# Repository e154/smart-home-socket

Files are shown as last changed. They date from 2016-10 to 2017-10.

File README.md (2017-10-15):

Автомат управления розетками/нагрузками
---------------------------------------

[Project site](https://e154.github.io/smart-home/) |
[Server](https://github.com/e154/smart-home/) |
[Configurator](https://github.com/e154/smart-home-configurator/) |
[Node](https://github.com/e154/smart-home-node/) |
[Development Tools](https://github.com/e154/smart-home-tools/) |
[Smart home Socket](https://github.com/e154/smart-home-socket/)



##### Функции
    Контроль температуры силового блока
    Включение/Выключения по команде управляющего сервера
    Контроль наличия сети/фазы

##### Общение с сервером
    Общение происходит по линии связи rs485, с помощью модифицированного 
    протокола MODBUS ASCII

##### Поведение автомата

    состояния:
    включен/выключен

    температура:
    в пределах нормы
    за пределами нормы

    комманды консоли:
    запрос состояния
          температура
          фаза
          вкл/выкл
          максимальный предел температуры
    включить
    выключить

##### Список компонентов

    Qty Value            Device                  Package         Parts              Description          
    1                    CPOL-EUE2,5-6E          E2,5-6E         C12                POLARIZED CAPACITOR, 
    1                    LEDCHIPLED_0805         CHIPLED_0805    LED2               LED                  
    5                    M01NOSILK-KIT           1X01NS-KIT      J1, J2, J3, J6, J7 Header 1             
    3                    M01PTH_NO_SILK_YES_STOP 1X01_NO_SILK    J4, J5, TEMP       Header 1             
    1                    MA03-2                  MA03-2          ISP                PIN HEADER           
    4                    MA04-1                  MA04-1          SV1, SV2, SV3, SV5 PIN HEADER           
    1   0.05mF           C-EUC0805               C0805           C6                 CAPACITOR, European  
    5   0.1              C-EUC0805               C0805           C1, C4, C5, C7, C8 CAPACITOR, European  
    2   10K              R-EU_M0805              M0805           R8, R12            RESISTOR, European s 
    3   10K              R-EU_R0805              R0805           R1, R13, R14       RESISTOR, European s 
    1   120R             R-EU_R0805              R0805           R17                RESISTOR, European s 
    1   16MHz            CRYSTALHC49U70          HC49U70         Q1                 CRYSTAL              
    1   1K               R-EU_M0805              M0805           R10                RESISTOR, European s 
    1   1K               R-EU_M1206              M1206           R9                 RESISTOR, European s 
    1   1K               R-EU_R0805              R0805           R2                 RESISTOR, European s 
    2   22p              C-EUC0805               C0805           C2, C3             CAPACITOR, European  
    3   330              R-EU_M0805              M0805           R3, R4, R5         RESISTOR, European s 
    1   560K             R-EU_M0805              M0805           R7                 RESISTOR, European s 
    2   560R             R-EU_R0805              R0805           R15, R16           RESISTOR, European s 
    1   78L05Z           78L05Z                  TO92            IC3                Positive VOLTAGE REG 
    2   82K              R-EU_0309/10            0309/10         R6, R11            RESISTOR, European s 
    1   AZ8-FORM-C       AZ8-FORM-C              AZ8             K1                 MINIATURE PC BOARD R 
    2   BC847            NPNSOT23                SOT-23          T2, T3             NPN TRANSISTOR       
    1   BT138-V          BT138-V                 TO220BV         T1                 TRIAC                
    2   DBDB101G         DBDB101G                DB              B1, B2             Single Phase 1.0 AMP 
    1   F/TMB            F/TMB                   F/TMB           SG1                BUZZER Source: Buerk 
    1   MAX481CSA        MAX481CSA               SO08            IC2                RS485 TRANSEIVER     
    1   MEGA48/88/168-AU MEGA48/88/168-AU        TQFP32-08       IC1                                     
    2   MKDSN1,5/2-5,08  MKDSN1,5/2-5,08         MKDSN1,5/2-5,08 X1, X2             MKDSN 1,5/ 2-5,08 Pr 
    1   MOC3031M         MOC3031M                DIL06           OK2                6-Pin DIP Zero-Cross 
    2   PC817            PC817                   DIL04           OK1, OK3           SHARP OPTO COUPLER   

##### Фоты
   
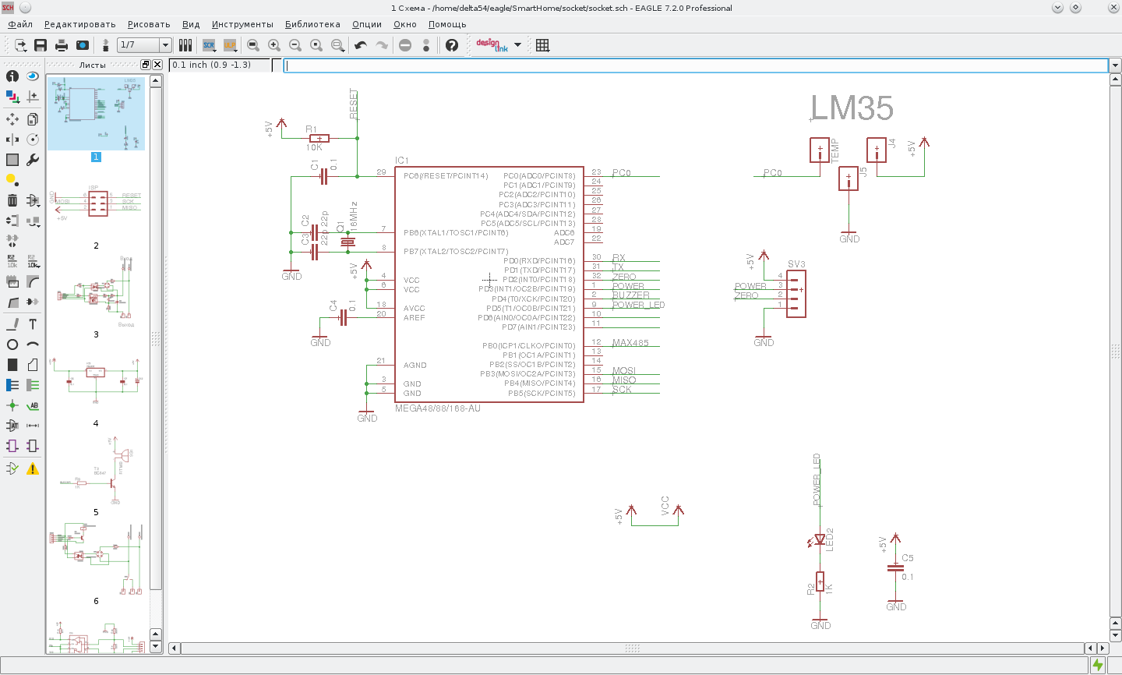
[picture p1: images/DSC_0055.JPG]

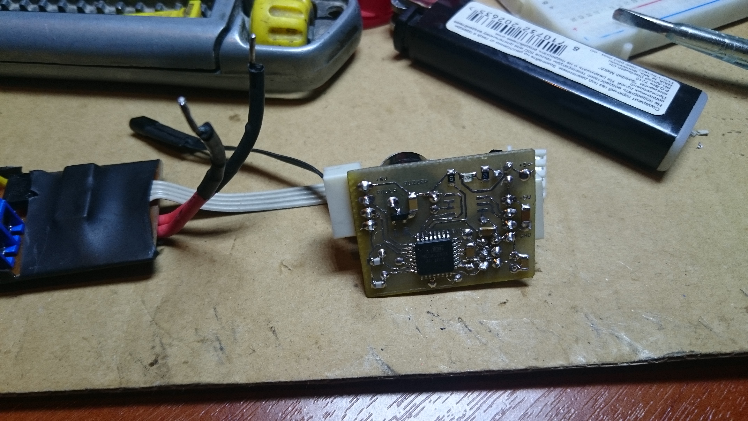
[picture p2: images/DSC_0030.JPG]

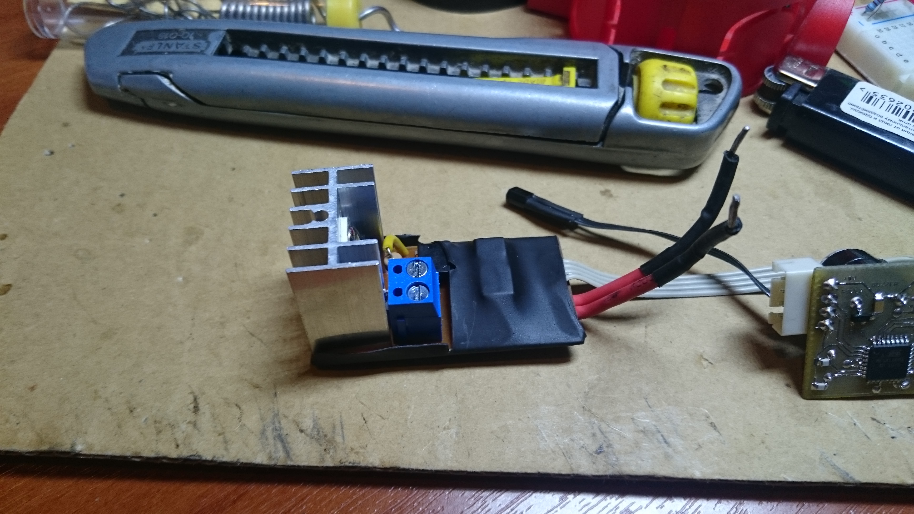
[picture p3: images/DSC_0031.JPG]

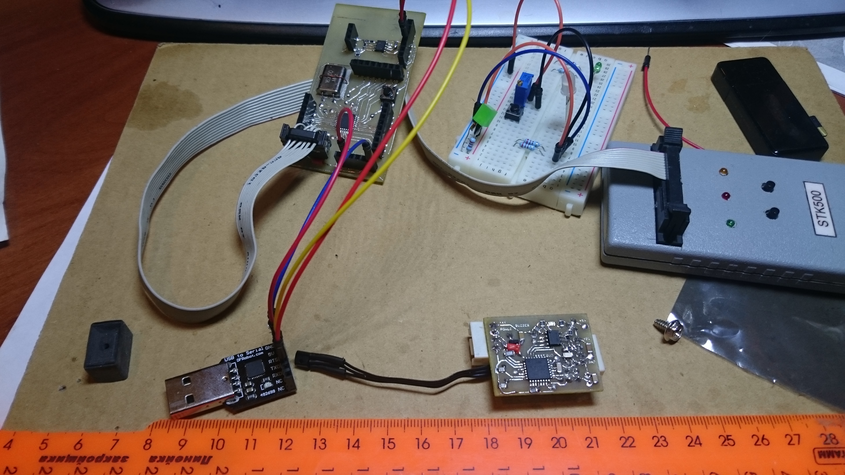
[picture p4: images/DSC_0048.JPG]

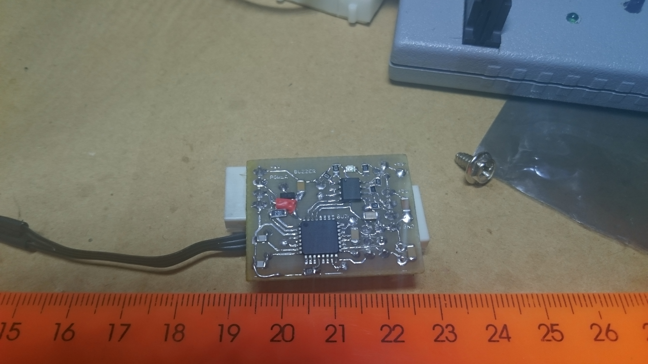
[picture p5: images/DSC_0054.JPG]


#### LICENSE

Smart home socket is licensed under the [MIT License (MIT)](https://github.com/e154/smart-home-socket/blob/master/LICENSE).

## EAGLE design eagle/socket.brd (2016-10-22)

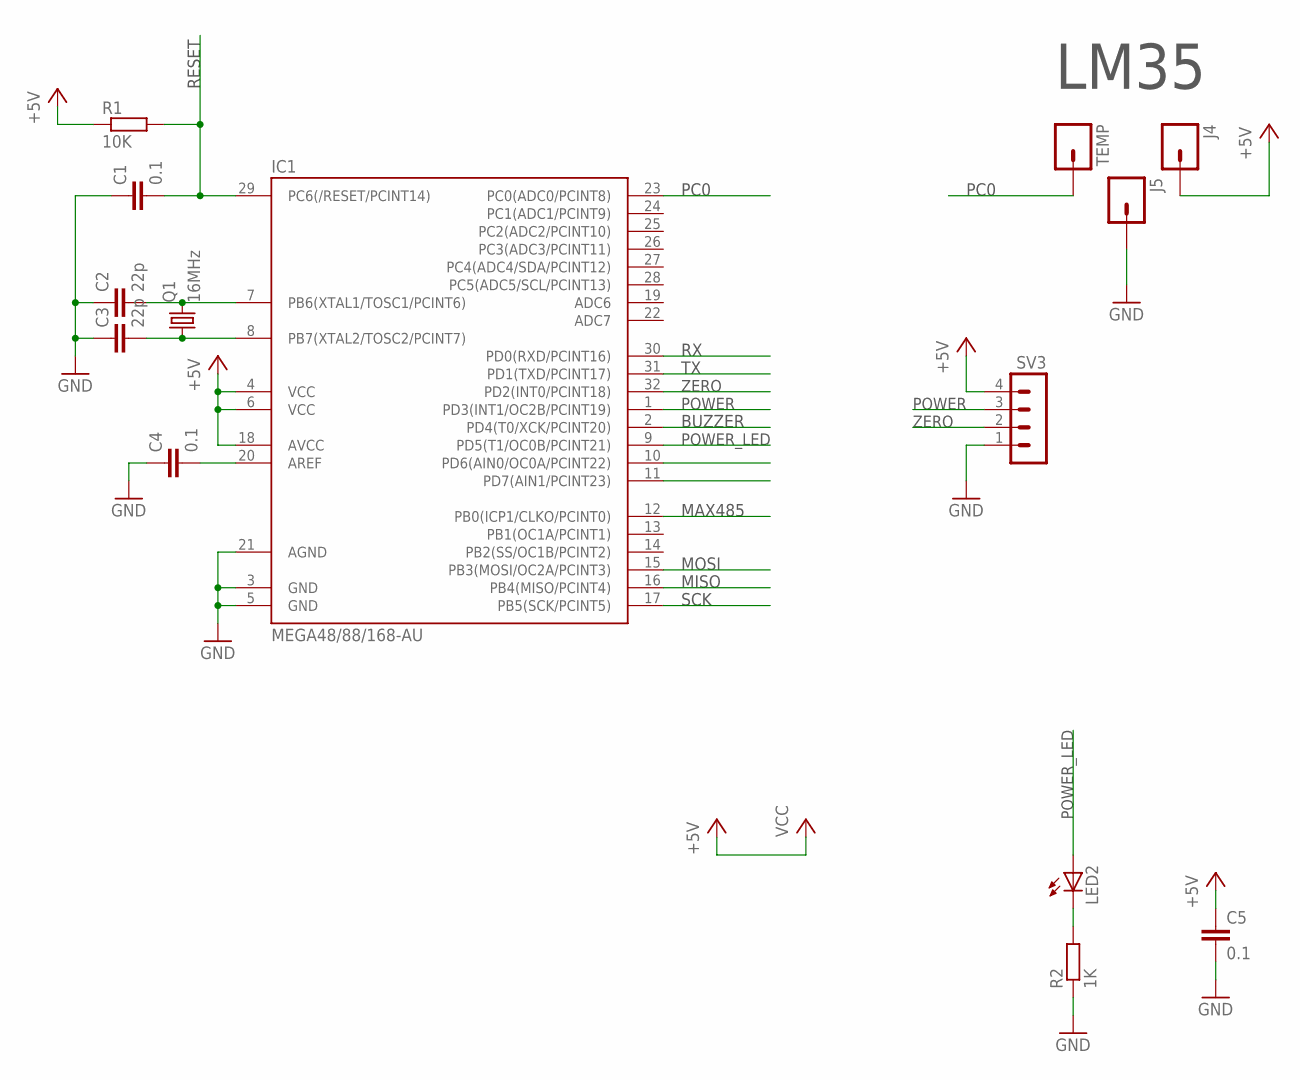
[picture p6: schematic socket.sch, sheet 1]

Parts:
C1, C4, C5: 0.1; C0805
C2, C3: 22p; C0805
IC1: MEGA48/88/168-AU; TQFP32-08
J4, J5: M01PTH_NO_SILK_YES_STOP; 1X01_NO_SILK
LED2: LEDCHIPLED_0805; CHIPLED_0805
Q1: 16MHz; HC49U70
R1: 10K; R0805
R2: 1K; R0805
SV3: MA04-1
TEMP: M01PTH_NO_SILK_YES_STOP; 1X01_NO_SILK

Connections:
+5V: C5.1, IC1.4 (VCC), IC1.6 (VCC), IC1.18 (AVCC), J4.1, R1.1, SV3.4; also elsewhere on the board
BUZZER: IC1.2 (PD4(T0/XCK/PCINT20)); also elsewhere on the board
GND: C1.1, C2.1, C3.1, C4.1, C5.2, IC1.3 (GND), IC1.5 (GND), IC1.21 (AGND), J5.1, R2.1, SV3.1; also elsewhere on the board
MISO: IC1.16 (PB4(MISO/PCINT4)); also elsewhere on the board
MOSI: IC1.15 (PB3(MOSI/OC2A/PCINT3)); also elsewhere on the board
unnamed: C4.2, IC1.20 (AREF)
unnamed: C2.2, IC1.7 (PB6(XTAL1/TOSC1/PCINT6)), Q1.2
unnamed: C3.2, IC1.8 (PB7(XTAL2/TOSC2/PCINT7)), Q1.1
unnamed: LED2.C, R2.2
PB0: IC1.12 (PB0(ICP1/CLKO/PCINT0)); also elsewhere on the board
PC0: IC1.23 (PC0(ADC0/PCINT8)), TEMP.1
PD3: IC1.1 (PD3(INT1/OC2B/PCINT19)), SV3.3
PD4: IC1.32 (PD2(INT0/PCINT18)), SV3.2
POWER_LED: IC1.9 (PD5(T1/OC0B/PCINT21)), LED2.A
RESET: C1.2, IC1.29 (PC6(/RESET/PCINT14)), R1.2; also elsewhere on the board
RX: IC1.30 (PD0(RXD/PCINT16)); also elsewhere on the board
SCK: IC1.17 (PB5(SCK/PCINT5)); also elsewhere on the board
TX: IC1.31 (PD1(TXD/PCINT17)); also elsewhere on the board

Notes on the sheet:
RESET
SCK
MISO
MOSI
MAX485
PC0
BUZZER
POWER
ZERO
LM35
POWER_LED

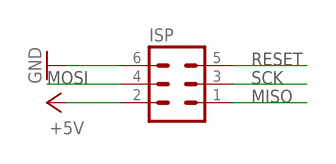
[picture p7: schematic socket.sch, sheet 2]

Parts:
ISP: MA03-2

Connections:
+5V: ISP.2; also elsewhere on the board
GND: ISP.6; also elsewhere on the board
MISO: ISP.1; also elsewhere on the board
MOSI: ISP.4; also elsewhere on the board
RESET: ISP.5; also elsewhere on the board
SCK: ISP.3; also elsewhere on the board

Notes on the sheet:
RESET
SCK
MISO
MOSI

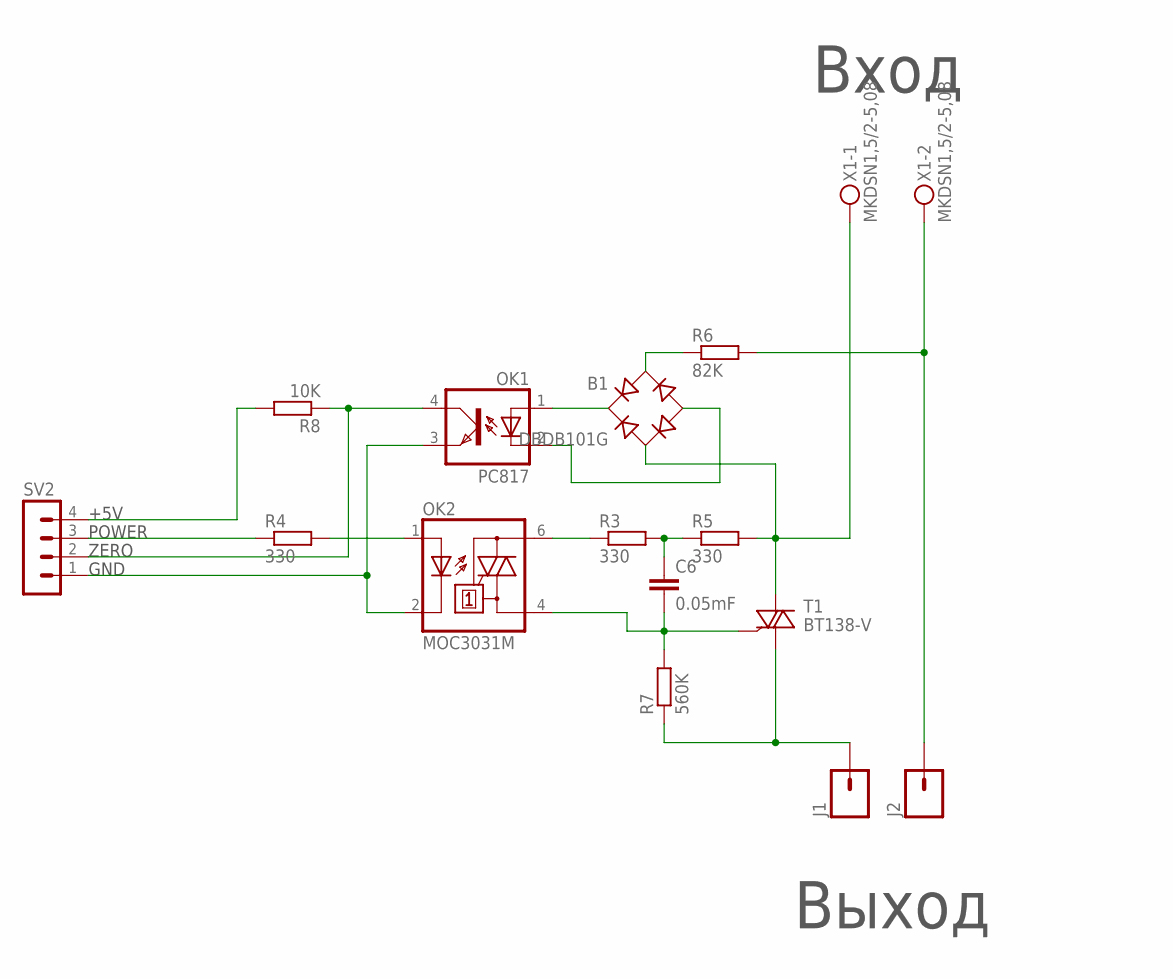
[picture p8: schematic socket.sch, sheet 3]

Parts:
B1: DBDB101G; DB
C6: 0.05mF; C0805
J1, J2: M01NOSILK-KIT; 1X01NS-KIT
OK1: PC817; DIL04
OK2: MOC3031M; DIL06
R3, R4, R5: 330; M0805
R6: 82K; 0309/10
R7: 560K; M0805
R8: 10K; M0805
SV2: MA04-1
T1: BT138-V; TO220BV
X1: MKDSN1,5/2-5,08

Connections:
unnamed: B1.AC2, R5.2, T1.T2 (A2), X1.1
unnamed: OK2.6 (A2), R3.1
unnamed: C6.2, OK2.4 (A1), R7.2, T1.G
unnamed: J1.1, R7.1, T1.T1 (A1)
unnamed: OK2.1 (A), R4.2
unnamed: J2.1, R6.2, X1.2
unnamed: C6.1, R3.2, R5.1
unnamed: B1.+, OK1.1 (A)
unnamed: B1.-, OK1.2 (C)
unnamed: B1.AC1, R6.1
unnamed: R8.2, SV2.4
unnamed: OK1.3 (EMIT), OK2.2 (C), SV2.1
POWER: R4.1, SV2.3
ZERO: OK1.4 (COL), R8.1, SV2.2

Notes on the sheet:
Вход
Выход
ZERO
POWER
+5V
GND

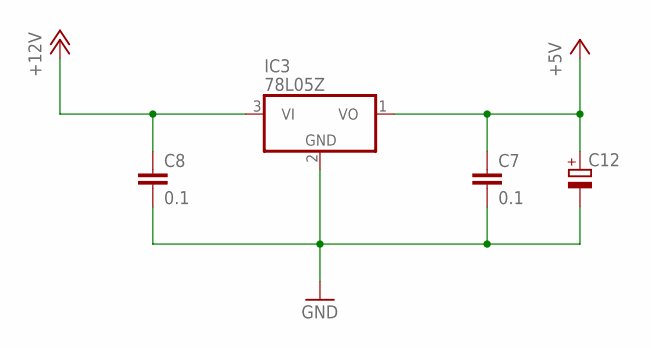
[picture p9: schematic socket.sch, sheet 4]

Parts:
C7, C8: 0.1; C0805
C12: CPOL-EUE2,5-6E; E2,5-6E
IC3: 78L05Z; TO92

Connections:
+5V: C7.1, C12.+, IC3.1 (VO); also elsewhere on the board
+12V: C8.1, IC3.3 (VI); also elsewhere on the board
GND: C7.2, C8.2, C12.-, IC3.2 (GND); also elsewhere on the board

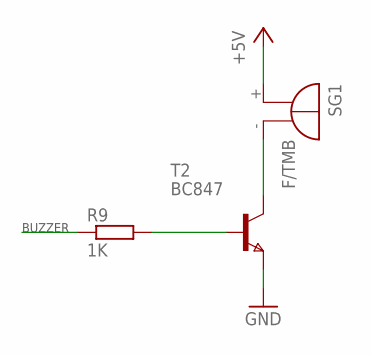
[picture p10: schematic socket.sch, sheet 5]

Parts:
R9: 1K; M1206
SG1: F/TMB
T2: BC847; SOT-23

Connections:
+5V: SG1.+; also elsewhere on the board
BUZZER: R9.1; also elsewhere on the board
GND: T2.2 (E); also elsewhere on the board
unnamed: R9.2, T2.3 (B)
SPEAKER-: SG1.-, T2.1 (C)

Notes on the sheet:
BUZZER

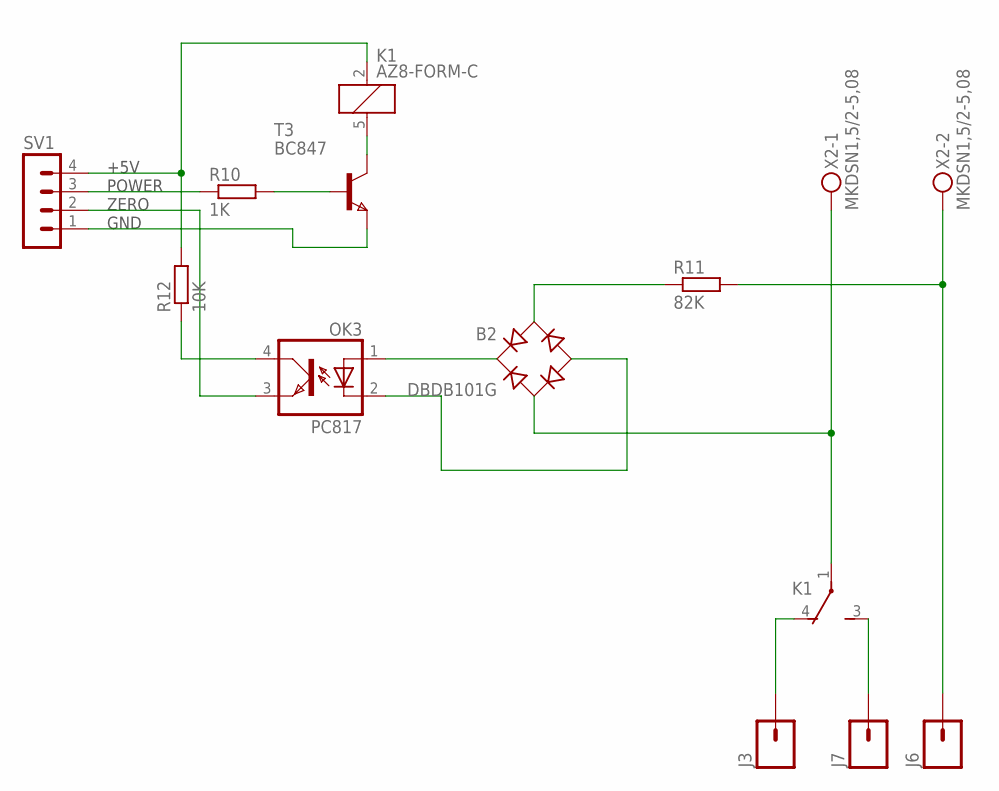
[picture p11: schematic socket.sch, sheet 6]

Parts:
B2: DBDB101G; DB
J3, J6, J7: M01NOSILK-KIT; 1X01NS-KIT
K1: AZ8-FORM-C; AZ8
OK3: PC817; DIL04
R10: 1K; M0805
R11: 82K; 0309/10
R12: 10K; M0805
SV1: MA04-1
T3: BC847; SOT-23
X2: MKDSN1,5/2-5,08

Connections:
unnamed: R10.1, SV1.3
unnamed: R10.2, T3.3 (B)
unnamed: K1.5 (2), T3.1 (C)
unnamed: K1.2 (1), R12.2, SV1.4
unnamed: J7.1, K1.3 (S)
unnamed: J3.1, K1.4 (O)
unnamed: J6.1, R11.2, X2.2
unnamed: SV1.1, T3.2 (E)
unnamed: OK3.4 (COL), R12.1
unnamed: OK3.3 (EMIT), SV1.2
unnamed: B2.+, OK3.1 (A)
unnamed: B2.-, OK3.2 (C)
unnamed: B2.AC1, R11.1
unnamed: B2.AC2, K1.1, X2.1

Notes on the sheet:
+5V
POWER
ZERO
GND

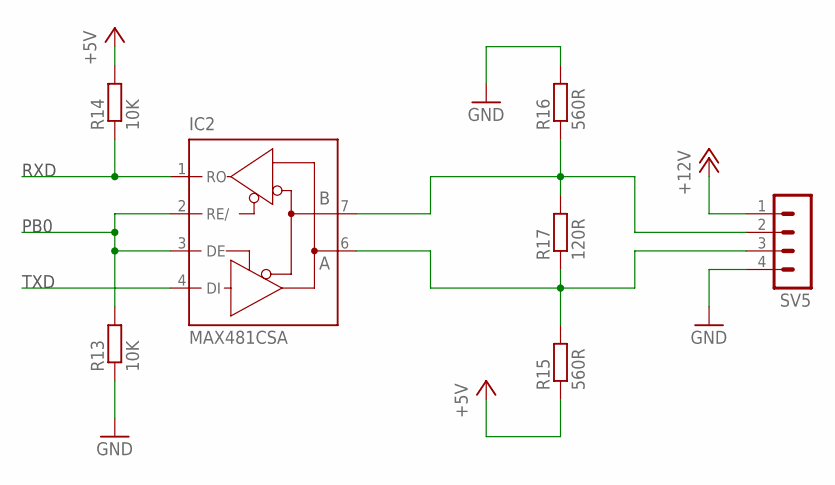
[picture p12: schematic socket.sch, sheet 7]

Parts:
IC2: MAX481CSA; SO08
R13, R14: 10K; R0805
R15, R16: 560R; R0805
R17: 120R; R0805
SV5: MA04-1

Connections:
+5V: IC2.8 (VCC), R14.2, R15.1; also elsewhere on the board
+12V: SV5.1; also elsewhere on the board
GND: IC2.5 (GND), R13.1, R16.2, SV5.4; also elsewhere on the board
unnamed: IC2.7 (B), R16.1, R17.2, SV5.2
unnamed: IC2.6 (A), R15.2, R17.1, SV5.3
PB0: IC2.2 (RE/), IC2.3 (DE), R13.2; also elsewhere on the board
RX: IC2.1 (RO), R14.1; also elsewhere on the board
TX: IC2.4 (DI); also elsewhere on the board

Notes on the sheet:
RXD
TXD
PB0

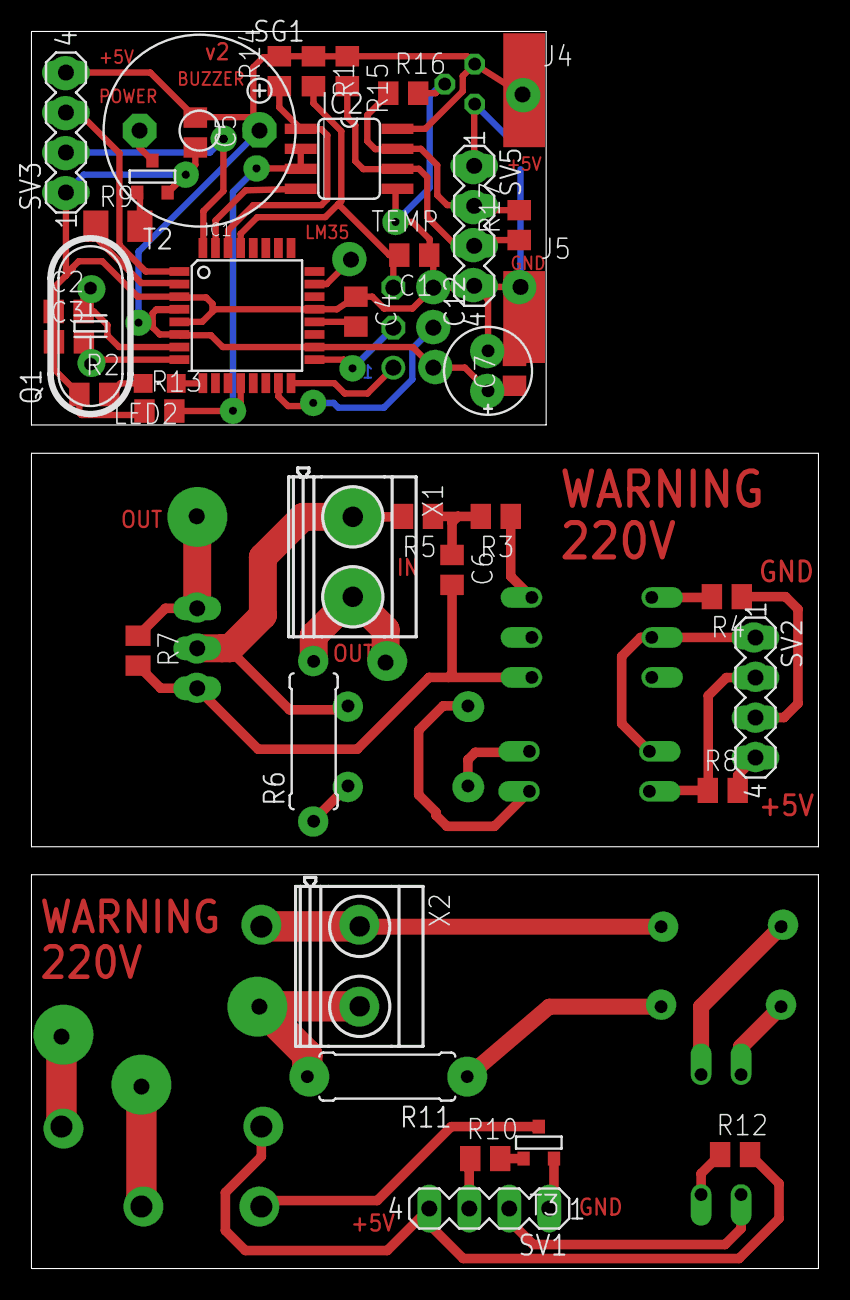
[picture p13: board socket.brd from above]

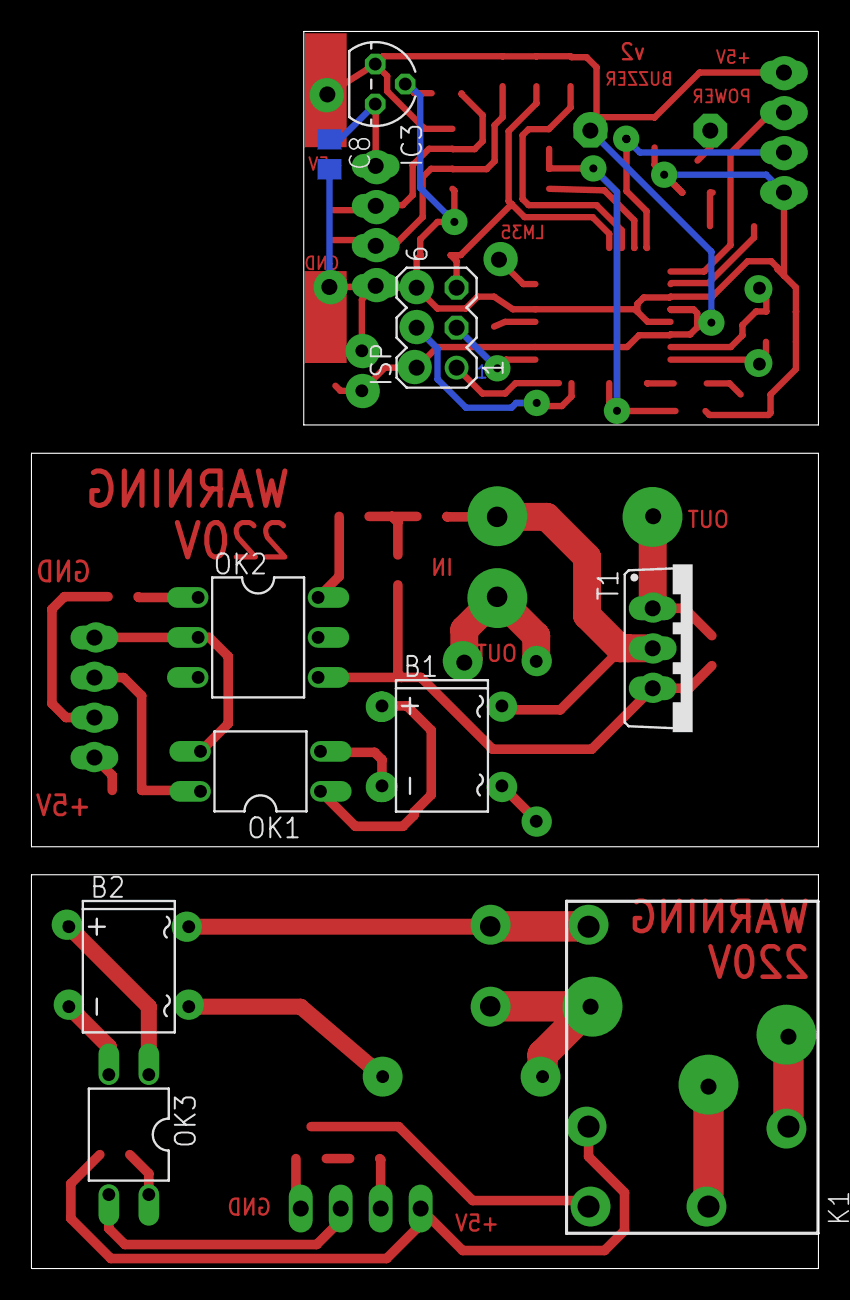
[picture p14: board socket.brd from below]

Board: 2 copper layers, 50.0 x 78.6 mm, 56 parts (10 on the bottom side), 51 nets.

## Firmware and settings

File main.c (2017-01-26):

#include <stdio.h>
#include "rtos/HAL.h"
#include "rtos/EERTOS.h"
#include "socket/uart.h"
#include "socket/socket.h"

//RTOS Interrupt
ISR(RTOS_ISR)
{
    TimerService();
}

#pragma clang diagnostic push
#pragma clang diagnostic ignored "-Wmissing-noreturn"
//==============================================================================
int main(void)
{
    InitAll();			// Инициализируем периферию
    InitRTOS();			// Инициализируем ядро
    RunRTOS();			// Старт ядра.
    SocketInit();

    while(1) 		    // Главный цикл диспетчера
    {
        wdt_reset();	// Сброс собачьего таймера
        TaskManager();	// Вызов диспетчера
    }
}
#pragma clang diagnostic pop

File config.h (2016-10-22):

//
// Created by delta54 on 9/30/16.
//

#ifndef CMAKE_AVR_CONFIG_H
#define CMAKE_AVR_CONFIG_H

#include <avr/io.h>

#define BUZZER_PORT         PORTD
#define BUZZER_PIN          PD4
#define TOGGLE_PORT         PORTD
#define TOGGLE_PIN          PD3
#define PHAZE_PIN           PD2

#define TEMPER_PORT         PORTC
#define TEMPER_PIN          PC0

#define PWR_LED_PORT        PORTD
#define PWR_LED             PD5

#define MAX485_PORT         PORTB
#define MAX485_PIN          PB0
#define MAX_TEMP            1089 // 109C^

#define DEVICE_ADDRESS      0x01       /*!< Device address hex format. */

#endif //CMAKE_AVR_CONFIG_H

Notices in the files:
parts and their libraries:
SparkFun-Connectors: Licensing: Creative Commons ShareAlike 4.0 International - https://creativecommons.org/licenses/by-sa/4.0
